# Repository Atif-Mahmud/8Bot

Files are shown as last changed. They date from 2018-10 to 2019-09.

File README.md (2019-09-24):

<h1 align="center">
    <br>
    <a href="#">8Bot</a>
    <br>
    8Bot
    <br>
</h1>



<h4 align="center">Autonomous Pool Robot using Computer Vision</h4>

<h5 align="center">By: Atif Mahmud and Ethan Guo</h5>

<p align="center">
    <a href="http://python.org/">
        
    </a>
    <a href="#">
        
    </a>
    <a href="#">
        
    </a>
</p>

<p align="center">
    <a href="#procedures">Background and Motivation</a> •
    <a href="#procedures">Procedures</a> •
    <a href="#related-works">Related Works</a> •
    <a href="#learning-goals">Learning Goals</a> •
    <a href="#engineering-goals">Engineering Goals</a> •
    <a href="#license">License</a>
</p>

# Background and Motivation

# Procedures
## Dependencies
### Python Libraries
The projects primary language is python. Input parsing, computer vision, and
pathfinding are executed by python clients. The
[OpenCV-Python](https://docs.opencv.org/3.4.3/index.html) wrapper is used along
with [Numpy](http://www.numpy.org/) to do the various computer vision and
matrix operations this project employs.

#### Install Python-OpenCV
```shell
sudo apt-get install python-opencv
```

#### Install Pip
```shell
sudo apt-get install python-pip
```

#### Install Numpy
```shell
pip install numpy
```

### MQTT Broker
This project relies on low latency publisher/subscriber based data transfer. To
do this we employ MQTT. MQTT (Message Queuing Telemetry Transport) is an ISO
Standard messaging protocol commonly used in IOT applications. The one caveat
is that its publish/subscriber message pattern requires a persistent broker.
For the purposes of this project we employ the open source MQTT broker [Eclipse
Mosquitto](https://mosquitto.org).

#### Install Broker (Ubuntu)

(Ubuntu 12^)
```shell
sudo apt install mosquitto
```

(Older versions of Ubuntu)
```shell
sudo apt-add-repository ppa:mosquitto-dev/mosquitto-ppa
sudo apt-get update
```

#### Install Python MQTT Client Library
```shell
pip install paho-mqtt
```

# Learning Goals
- [ ] Continuous Integration
- [x] MQTT Protocol

# Engineering Goals
- [ ] Fast robot messaging infrastructure
- [ ] Robust object classification
- [ ] Robust environment description
- [ ] Robust localization

# Related Works

# License

GNU GENERAL PUBLIC LICENSE
Version 3, 29 June 2007

Refer to LICENSE.txt for full details

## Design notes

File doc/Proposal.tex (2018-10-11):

\documentclass[11pt]{article}
\usepackage[margin=1in]{geometry}
\usepackage[utf8]{inputenc}
\setlength{\parskip}{8pt}
\setlength{\parindent}{0pt}
\usepackage{titling}
\setlength{\droptitle}{-1in}

\usepackage{titlesec}
\titlespacing\section{0pt}{0pt plus 4pt minus 4pt}{0pt plus 4pt minus 4pt}
\titlespacing\subsection{0pt}{0pt plus 4pt minus 4pt}{0pt plus 4pt minus 4pt}
\titlespacing\subsubsection{0pt}{0pt plus 4pt minus 4pt}{0pt plus 4pt minus 4pt}

\title{SE101 Lab Project Proposal \vspace{-12pt}}
\author{Ethan Guo, Atif Mahmud \hskip 5em 11 October 2018}
\date{\vspace{-12pt}}

\begin{document}
\pagenumbering{gobble}

\maketitle
\vspace{-0.625in}

\section*{Introduction}

We aim to create a small mobile robot capable of playing pool.

Ideally, the end goal will be a robot with a wheeled base that travels across the surface of the pool table to line up with the cue ball, then use a solenoid actuator to shoot the cue ball such that it hits another pool ball into a pocket. This will be accomplished with the help of a overhead camera mounted above the pool table. 

\section*{Software}

We will structure our software components into nodes, based loosely on the ROS paradigm. The computer vision node will take in camera input and use OpenCV to determine the position of the robot and pool balls. The robot control node, written in Python, will perform pathfinding, and send commands to move the robot. Finally, the user interface node, written using Angular will display the current board environment from the computer vision node and send REST requests to the robot control node to preform actions.

\section*{Hardware}

We will be using the following hardware (* denotes items we need to purchase):
\begin{itemize}
    \setlength{\itemsep}{0pt} %
    \setlength{\parskip}{0pt} %
    \setlength{\parsep}{0pt} %
    \vspace{-0.125in}
    \item Arduino Uno or Nano microcontroller
    \item HC-05 Bluetooth Transceiver
    \item Solenoid actuator to shoot cue balls *
    \item $4 \times$ Robotshop gear motors or continuous servos *
    \item $4 \times$ Robotshop omni wheels *
    \item USB webcam *
\end{itemize}

\vspace{-8pt}
Time-permitting, we would ideally like to design and fabricate a PCB to integrate all the circuitry.

\section*{Challenges}

On the software side, the biggest challenge will be in the computer vision task. This includes detecting and locating pool balls and the robot itself, and most critically, classifying striped vs. solid balls.
Fortunately, the pool table is a relatively easy environment for computer vision tasks, since the background is a static solid colour, and the objects are a consistent size and shape and mostly solid colours.

Another challenge will be writing the pathfinding and closed-loop control system to move the robot into the desired program, while navigating around obstacles (other pool balls).

On the hardware side, we will most likely need to build the robot base and drive system from scratch, which will be time-consuming and will likely require plenty of troubleshooting.

\section*{Prototype}

We will be building this project as a evolutionary prototype. With so many different systems to integrate, we will be working in a horizontal paradigm. By the prototype demo day, we aim to have a working mobile base, very basic functionality in each of the three major software components (computer vision, robot control, user interface), and a functional skeleton for communication between the relevant nodes (including the hardware components).

% https://github.com/patricklam/se101-f18/blob/master/lab/se101-lab-project.pdf

\end{document}

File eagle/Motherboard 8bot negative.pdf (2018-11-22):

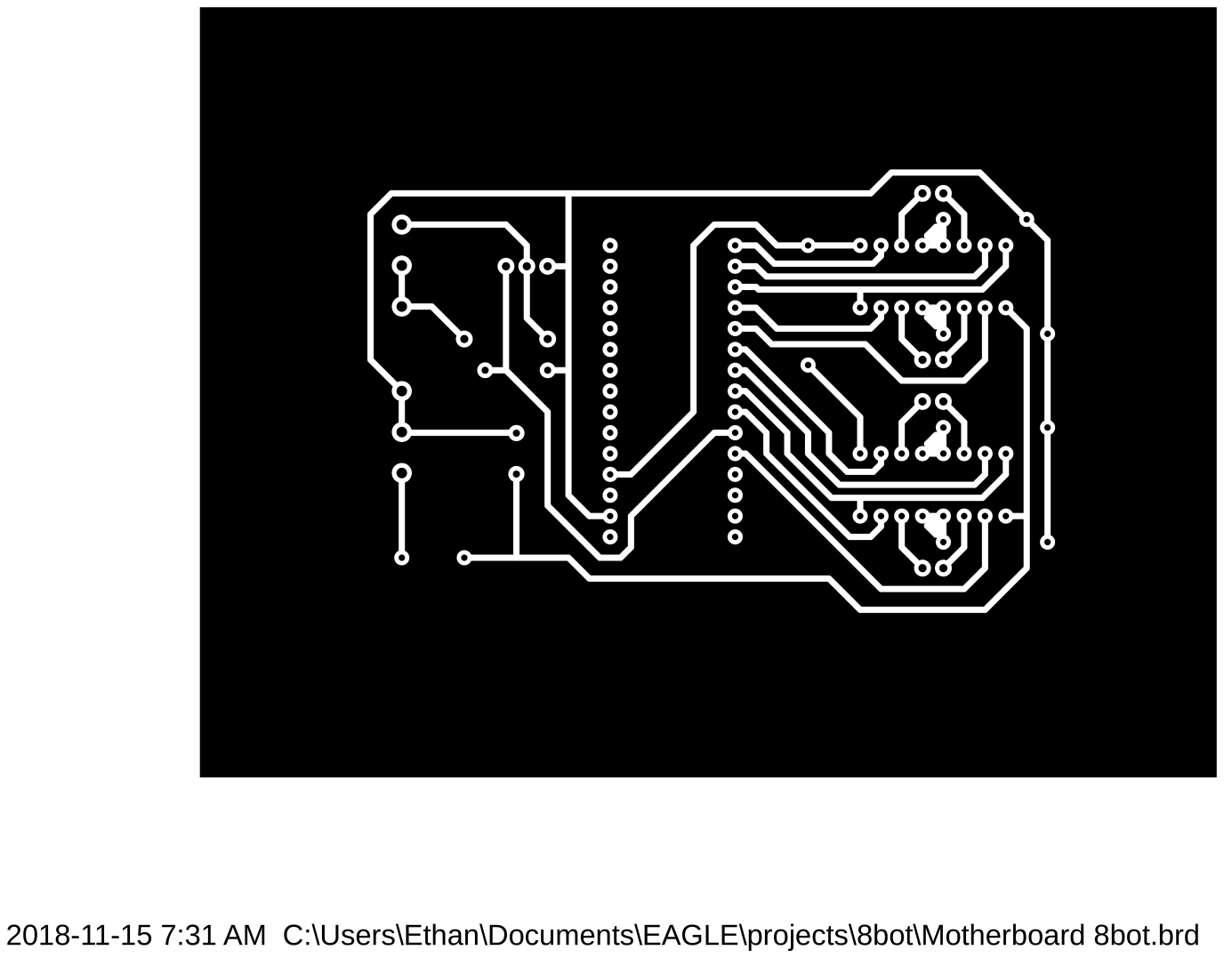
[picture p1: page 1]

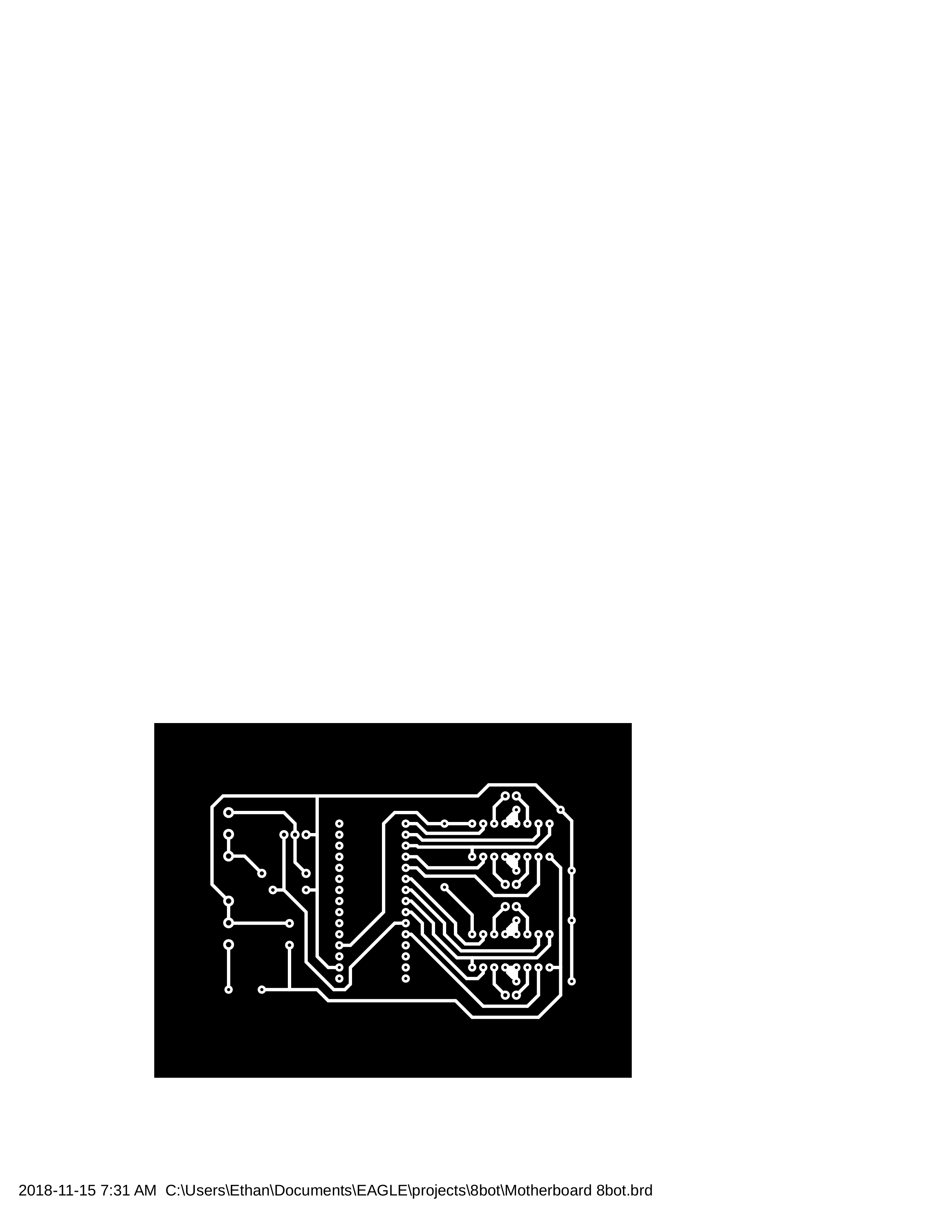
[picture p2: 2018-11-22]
eagle/Motherboard 8bot negative.png

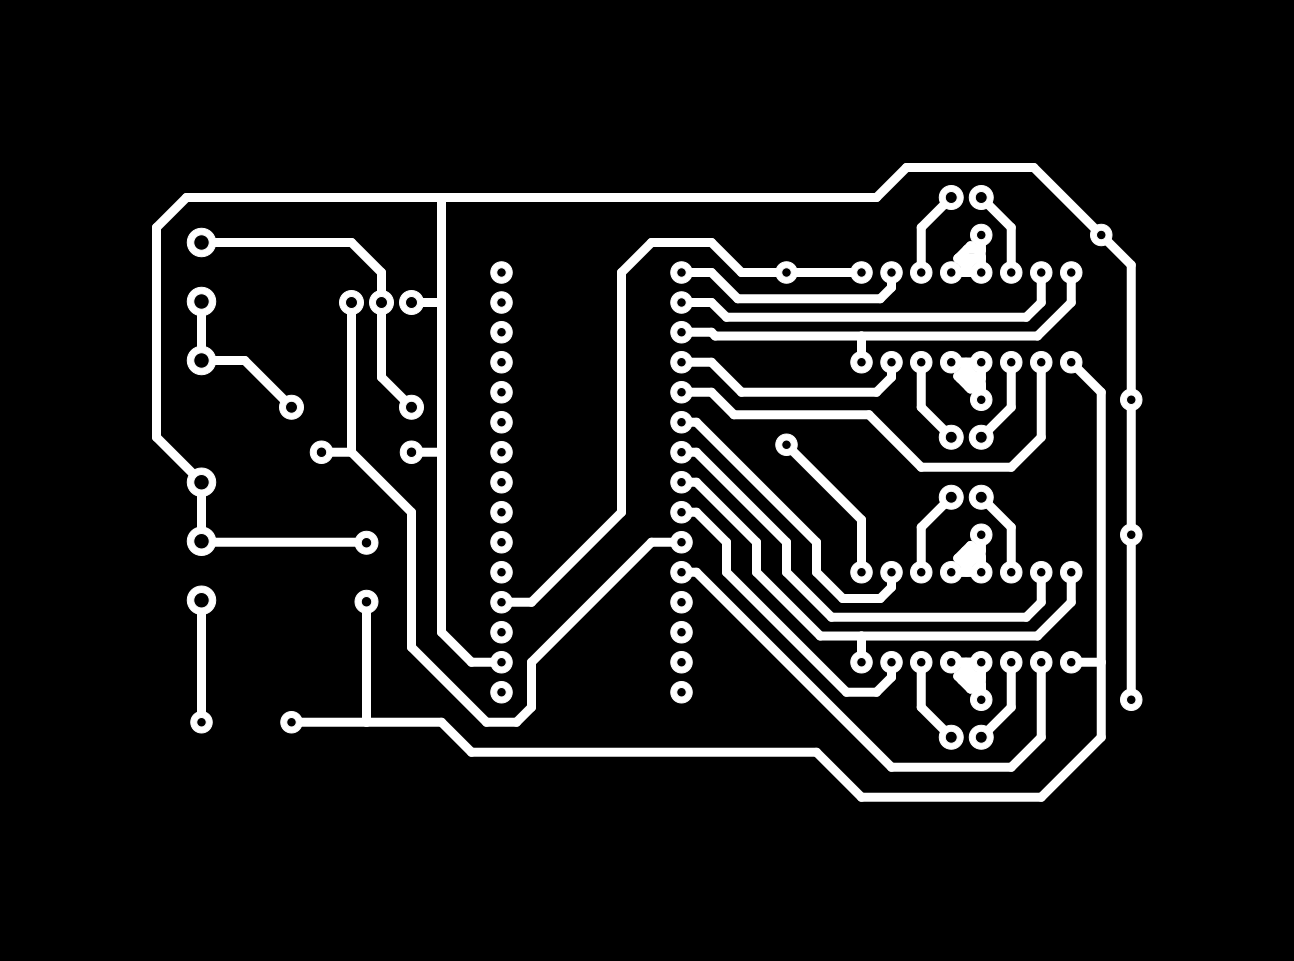
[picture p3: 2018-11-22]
eagle/Motherboard 8bot negative isolated.png

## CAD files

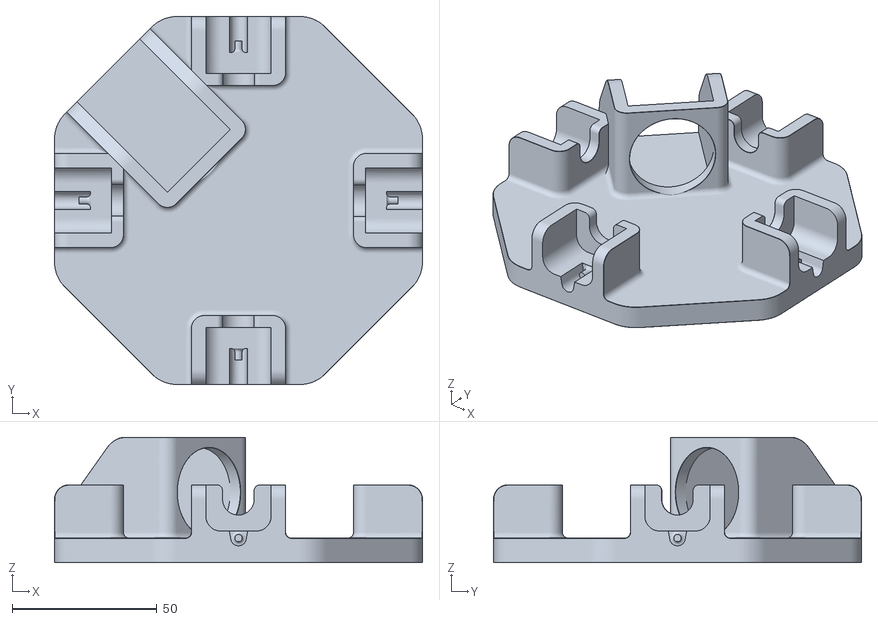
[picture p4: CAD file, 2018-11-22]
3D Models/Frame.stl
127.3 x 127.3 x 43.4

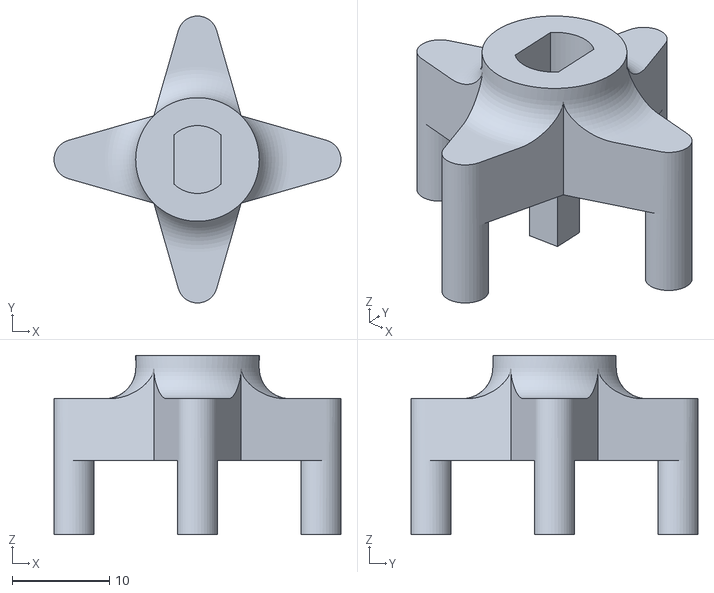
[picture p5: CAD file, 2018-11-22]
3D Models/Wheel Mount.stl
29.5 x 29.5 x 18.4

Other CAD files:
3D Models/Assembly.iam
3D Models/Frame.ipt
3D Models/Motor Solarbotics GM3/GM3-driver_side-1.ipt
3D Models/Motor Solarbotics GM3/GM3-encoder_side-1.ipt
3D Models/Motor Solarbotics GM3/GMstrap2.ipt
3D Models/Motor Solarbotics GM3/RM3-regular motor.ipt
3D Models/Motor Solarbotics GM3/Solarbotics-GM3.iam
3D Models/Motor Solarbotics GM3/encoder.ipt
3D Models/Motor Solarbotics GM3/output shaft.ipt
3D Models/Motor Solarbotics GM3/screw_head1.ipt
3D Models/Solenoid Arm.ipt
3D Models/Solenoid Body.ipt
3D Models/Solenoid.iam
3D Models/Solenoid.ipt
3D Models/Wheel Mount.ipt
3D Models/Wheel VEX 228-2536/228-2536-001-1.ipt
3D Models/Wheel VEX 228-2536/228-2536-002-1.ipt
3D Models/Wheel VEX 228-2536/228-2536-003-1.ipt
3D Models/Wheel VEX 228-2536/228-2536-004-1.ipt
3D Models/Wheel VEX 228-2536/ROLLER-2.iam
3D Models/Wheel VEX 228-2536/Wheel VEX 228-2536.iam

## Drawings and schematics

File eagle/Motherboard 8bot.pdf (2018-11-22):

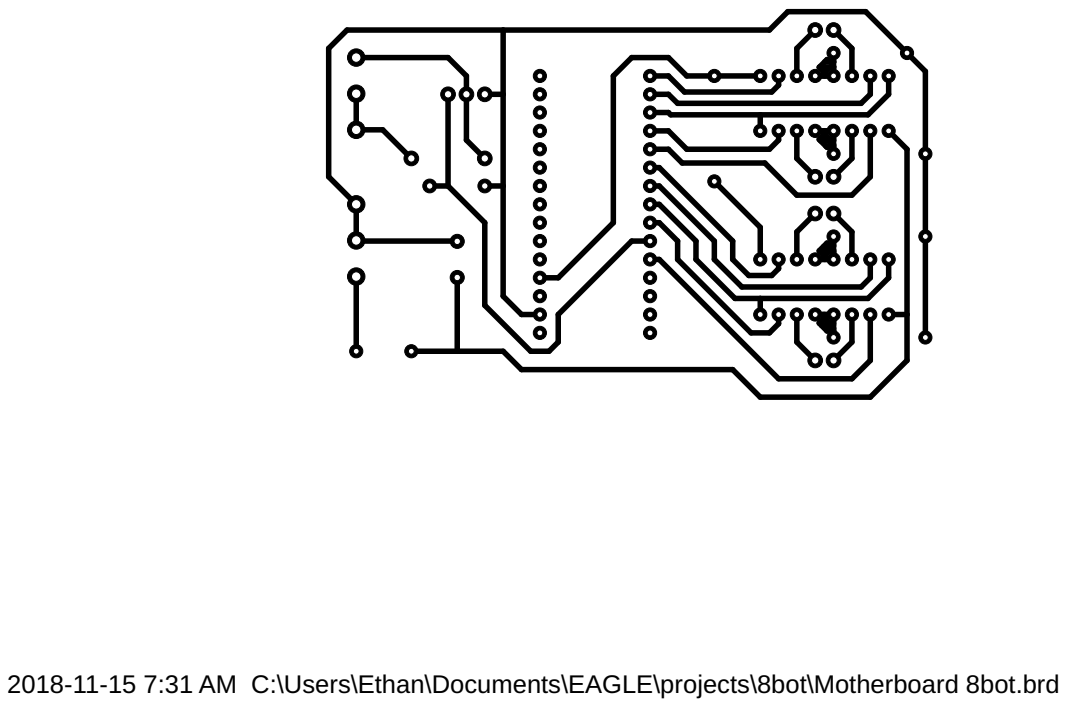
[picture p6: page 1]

2018-11-15 7:31 AM C:\Users\Ethan\Documents\EAGLE\projects\8bot\Motherboard 8bot.brd

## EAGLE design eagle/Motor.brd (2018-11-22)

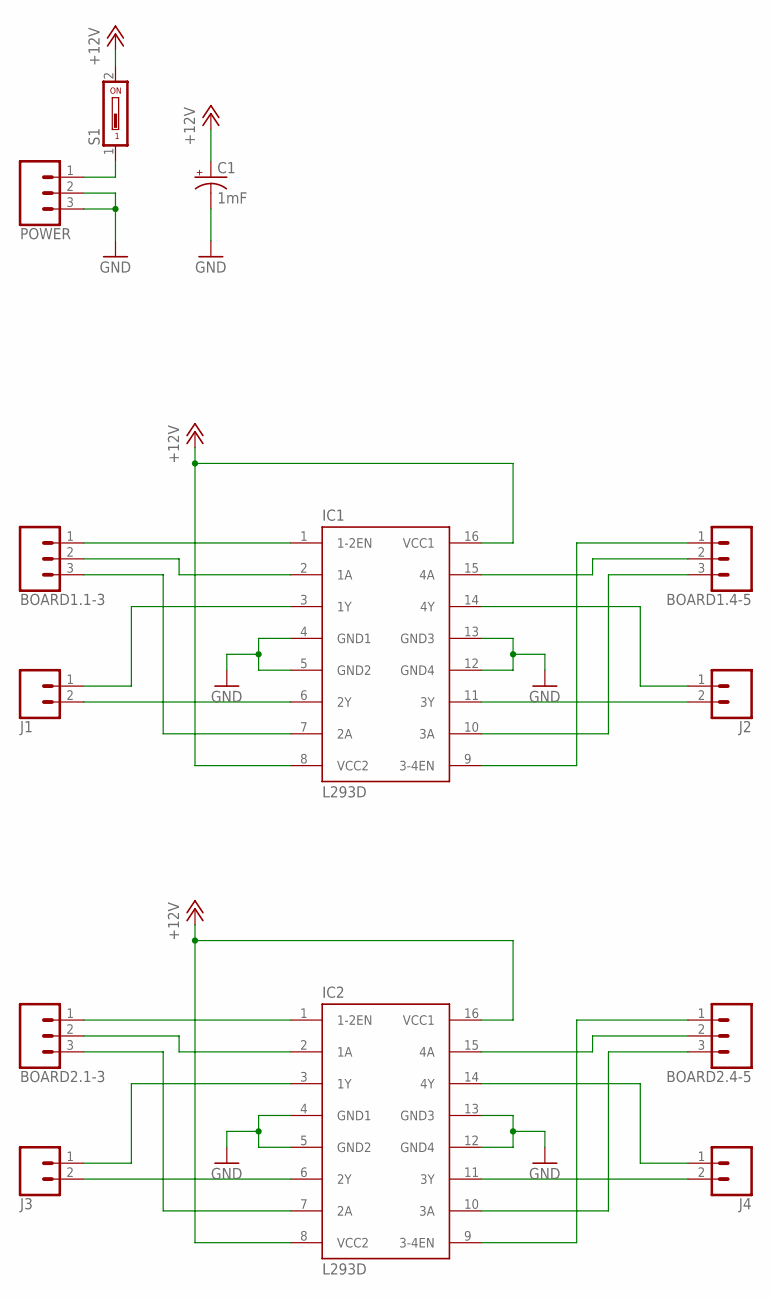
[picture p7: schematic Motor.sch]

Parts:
BOARD1.1-3, BOARD1.4-5, BOARD2.1-3, BOARD2.4-5: CONN_03; 1X03
C1: 1mF; CPOL-RADIAL-5MM-10MM
IC1, IC2: L293D; DIL16
J1, J2, J3, J4: CONN_02; 1X02
POWER: CONN_03; 1X03
S1: DS01; DS-01

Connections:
+9V: C1.+, IC1.8 (VCC2), IC1.16 (VCC1), IC2.8 (VCC2), IC2.16 (VCC1), S1.2
EN1: BOARD1.1-3.1, IC1.1 (1-2EN)
EN2: BOARD2.1-3.1, IC2.1 (1-2EN)
GND: C1.-, IC1.4 (GND1), IC1.5 (GND2), IC1.12 (GND4), IC1.13 (GND3), IC2.4 (GND1), IC2.5 (GND2), IC2.12 (GND4), IC2.13 (GND3), POWER.2, POWER.3
unnamed: IC1.3 (1Y), J1.1
unnamed: IC1.6 (2Y), J1.2
unnamed: IC1.14 (4Y), J2.1
unnamed: IC1.11 (3Y), J2.2
unnamed: BOARD1.1-3.2, IC1.2 (1A)
unnamed: BOARD1.1-3.3, IC1.7 (2A)
unnamed: BOARD1.4-5.3, IC1.10 (3A)
unnamed: BOARD1.4-5.2, IC1.15 (4A)
unnamed: IC2.3 (1Y), J3.1
unnamed: IC2.6 (2Y), J3.2
unnamed: IC2.14 (4Y), J4.1
unnamed: IC2.11 (3Y), J4.2
unnamed: BOARD2.1-3.2, IC2.2 (1A)
unnamed: BOARD2.1-3.3, IC2.7 (2A)
unnamed: BOARD2.4-5.1, IC2.9 (3-4EN)
unnamed: BOARD1.4-5.1, IC1.9 (3-4EN)
unnamed: BOARD2.4-5.3, IC2.10 (3A)
unnamed: BOARD2.4-5.2, IC2.15 (4A)
unnamed: POWER.1, S1.1

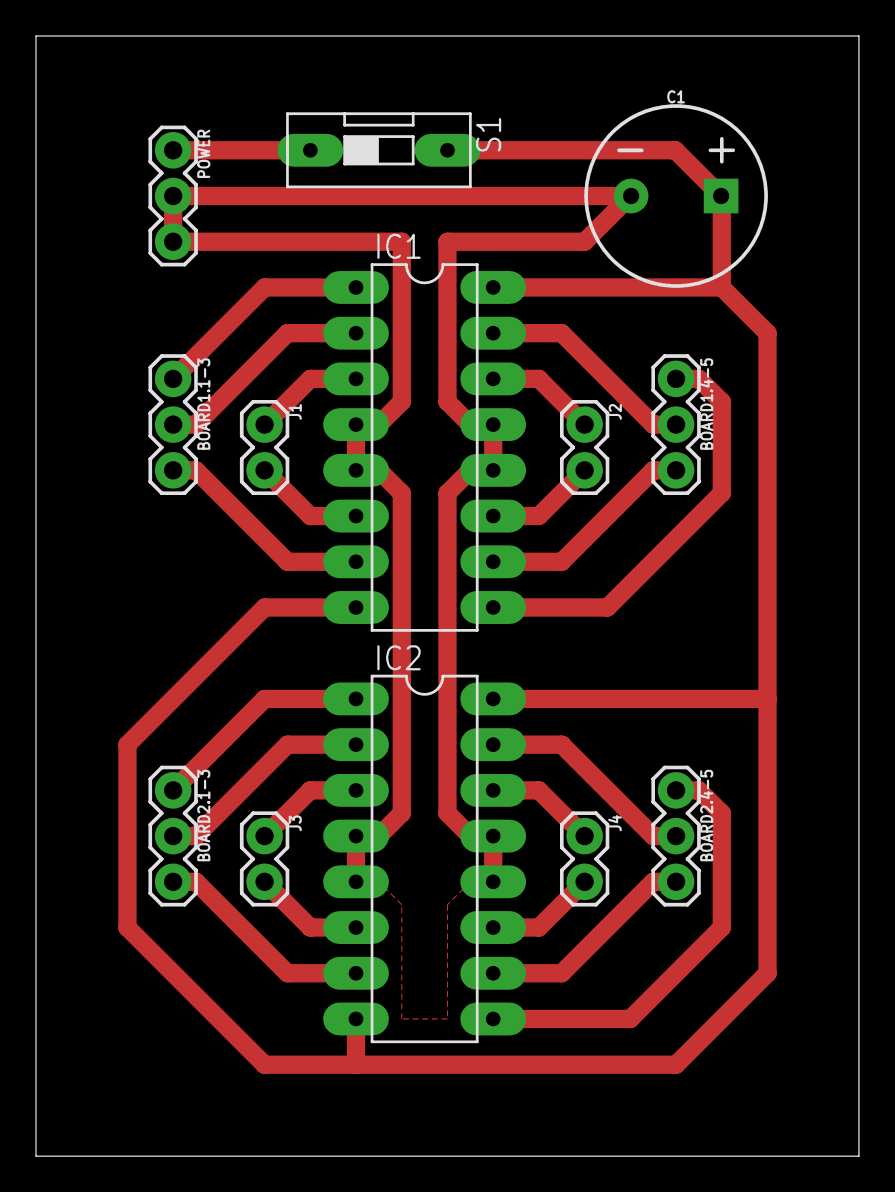
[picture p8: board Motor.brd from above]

Board: 2 copper layers, 45.7 x 62.2 mm, 13 parts (0 on the bottom side), 23 nets.

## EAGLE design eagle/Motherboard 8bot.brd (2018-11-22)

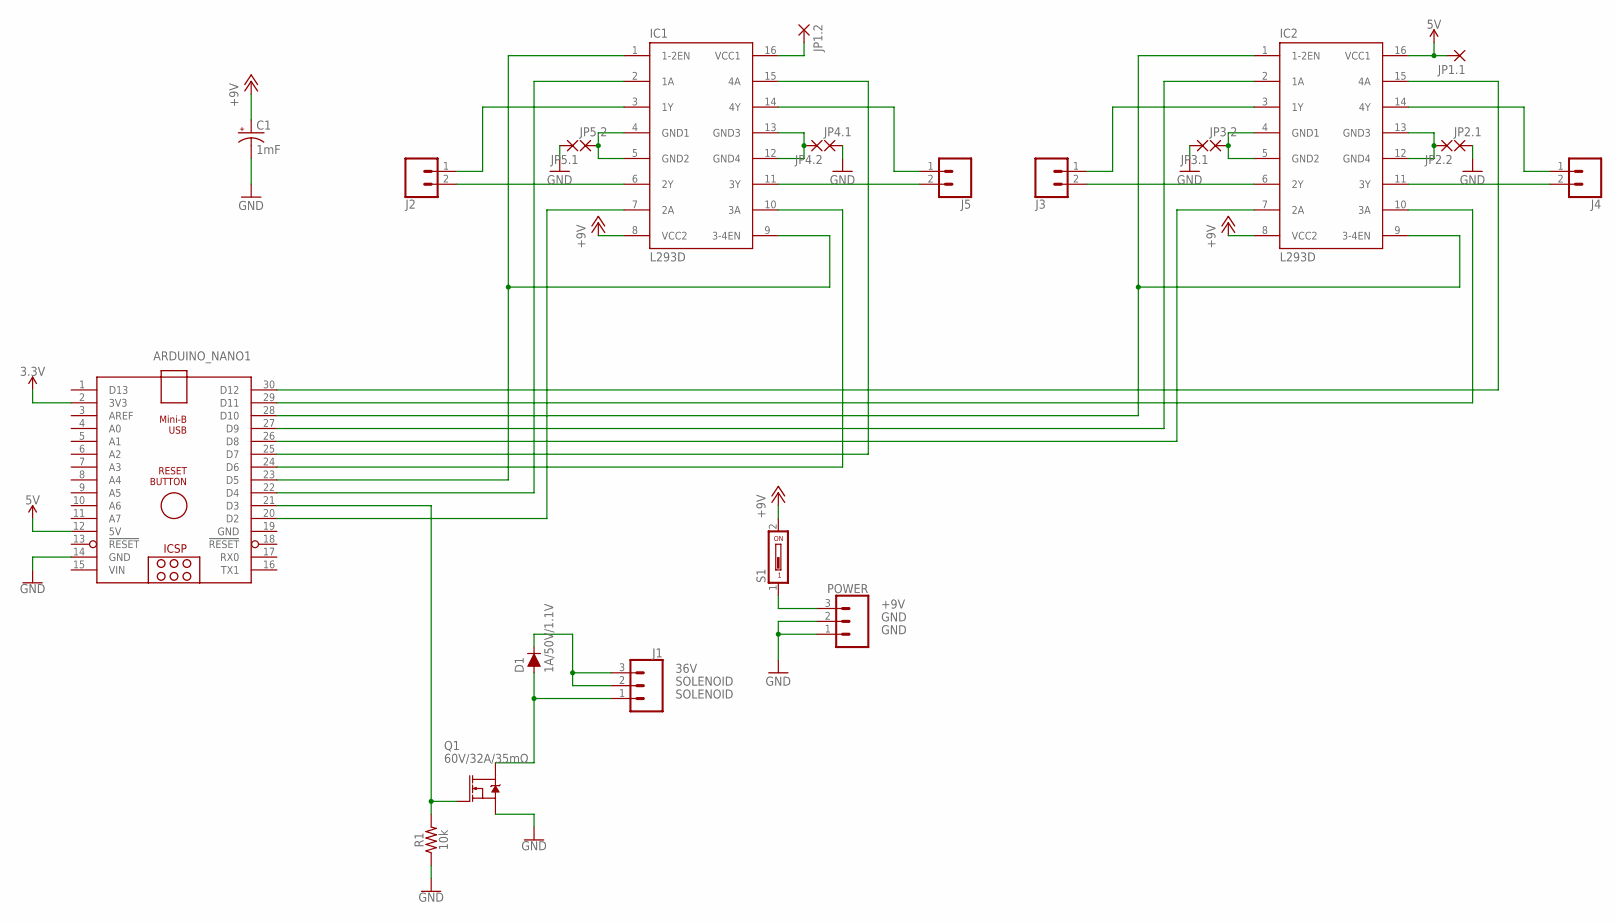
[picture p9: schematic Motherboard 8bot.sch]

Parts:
ARDUINO_NANO1: ARDUINO_NANO
C1: 1mF; CPOL-RADIAL-5MM-10MM
D1: 1A/50V/1.1V; DIODE-1N4001
IC1, IC2: L293D; DIL16
J1: CONN_03-SCREW-5MM; SCREWTERMINAL-5MM-3
J2, J3, J4, J5: CONN_02; 1X02
JP1.1, JP1.2, JP2.1, JP2.2, JP3.1, JP3.2, JP4.1, JP4.2, JP5.1, JP5.2: 1,6/0,8
POWER: CONN_03-SCREW-5MM; SCREWTERMINAL-5MM-3
Q1: 60V/32A/35mΩ; TO220V
R1: 10k; AXIAL-0.3
S1: DS01; DS-01

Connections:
3.3V: ARDUINO_NANO1.2 (3V3)
5V: ARDUINO_NANO1.12 (5V), IC2.16 (VCC1), JP1.1.1
36V: D1.C, J1.2, J1.3
+9V: C1.+, IC1.8 (VCC2), IC2.8 (VCC2), S1.2
EN1: ARDUINO_NANO1.23 (D5), IC1.1 (1-2EN), IC1.9 (3-4EN)
EN2: ARDUINO_NANO1.28 (D10), IC2.1 (1-2EN), IC2.9 (3-4EN)
GND: ARDUINO_NANO1.14 (GND), ARDUINO_NANO1.19 (GND), C1.-, JP2.1.1, JP3.1.1, JP4.1.1, JP5.1.1, POWER.1, POWER.2, Q1.3 (S), R1.P$1 (1)
unnamed: ARDUINO_NANO1.21 (D3), Q1.1 (G), R1.P$2 (2)
unnamed: IC1.3 (1Y), J2.1
unnamed: IC1.6 (2Y), J2.2
unnamed: IC1.14 (4Y), J5.1
unnamed: IC1.11 (3Y), J5.2
unnamed: ARDUINO_NANO1.20 (D2), IC1.7 (2A)
unnamed: ARDUINO_NANO1.22 (D4), IC1.2 (1A)
unnamed: ARDUINO_NANO1.24 (D6), IC1.10 (3A)
unnamed: IC2.3 (1Y), J3.1
unnamed: IC2.6 (2Y), J3.2
unnamed: IC2.14 (4Y), J4.1
unnamed: IC2.11 (3Y), J4.2
unnamed: IC1.16 (VCC1), JP1.2.1
unnamed: ARDUINO_NANO1.27 (D9), IC2.2 (1A)
unnamed: ARDUINO_NANO1.25 (D7), IC1.15 (4A)
unnamed: ARDUINO_NANO1.29 (D11), IC2.10 (3A)
unnamed: ARDUINO_NANO1.26 (D8), IC2.7 (2A)
unnamed: ARDUINO_NANO1.30 (D12), IC2.15 (4A)
unnamed: IC1.4 (GND1), IC1.5 (GND2), JP5.2.1
unnamed: POWER.3, S1.1
unnamed: IC1.12 (GND4), IC1.13 (GND3), JP4.2.1
unnamed: IC2.4 (GND1), IC2.5 (GND2), JP3.2.1
unnamed: IC2.12 (GND4), IC2.13 (GND3), JP2.2.1
SOLENOID: D1.A, J1.1, Q1.2 (D)
VIN: ARDUINO_NANO1.15 (VIN)

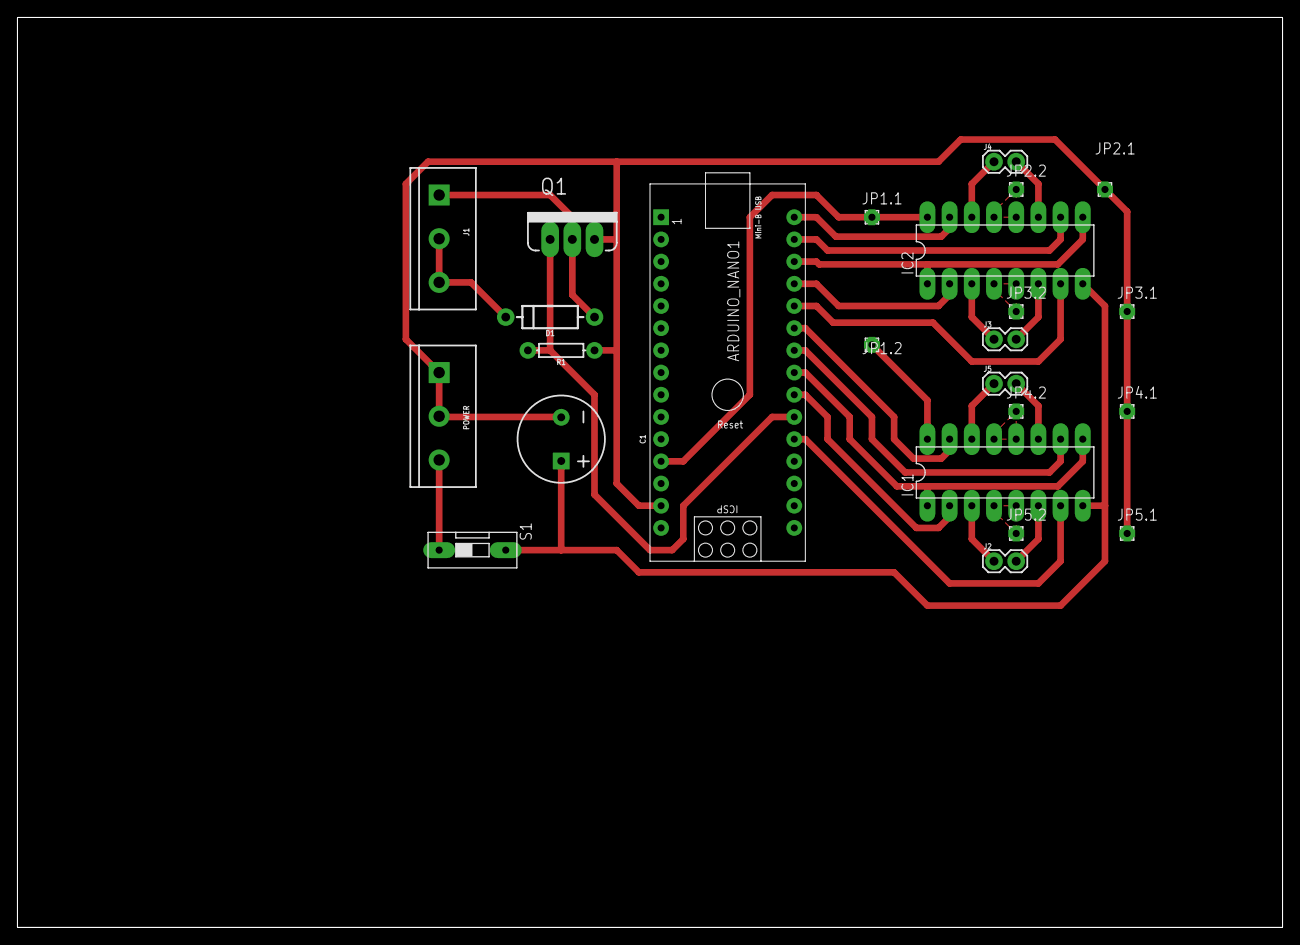
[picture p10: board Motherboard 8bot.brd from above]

Board: 2 copper layers, 144.8 x 104.1 mm, 24 parts (0 on the bottom side), 30 nets.

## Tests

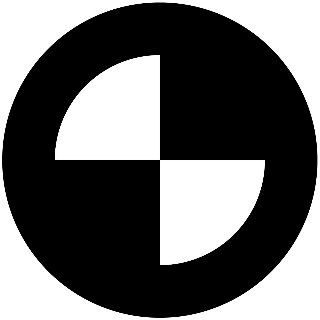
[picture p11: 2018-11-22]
computer_vision_node/img/calibration_320.png

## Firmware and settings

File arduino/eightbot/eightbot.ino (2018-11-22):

// #define DEBUG_ECHO


#define EN_12 5
#define M1_F  2
#define M1_B  4
#define M2_F  7
#define M2_B  6

#define EN_34 10
#define M3_F  9
#define M3_B  8
#define M4_F  11
#define M4_B  12

#define SOLENOID  3
#define LED  13

#define SOLENOID_DURATION 500 // ms

#define GET_BIT(c, bit) (c >> bit & 1)

int solenoid_timer = 0;

char command = 0;
char data = 0;

void setup() {
  pinMode(EN_12, OUTPUT);
  pinMode(M1_F, OUTPUT);
  pinMode(M1_B, OUTPUT);
  pinMode(M2_F, OUTPUT);
  pinMode(M2_B, OUTPUT);
  pinMode(EN_34, OUTPUT);
  pinMode(M3_F, OUTPUT);
  pinMode(M3_B, OUTPUT);
  pinMode(M4_F, OUTPUT);
  pinMode(M4_B, OUTPUT);
  pinMode(SOLENOID, OUTPUT);
  pinMode(LED, OUTPUT);

  digitalWrite(EN_12, HIGH);
  digitalWrite(EN_34, HIGH);

  Serial.begin(9600);
  Serial.println("8bot");
}

void loop() {
  if (Serial.available()) {
    if (command == 0) {
      command = Serial.read();
    }
    else {
      data = Serial.read();

      #ifdef DEBUG_ECHO
        Serial.print(command);
        Serial.print(" ");
        Serial.println(data);
      #endif

      if (command == 'M') {
        digitalWrite(M1_F, GET_BIT(data, 7));
        digitalWrite(M1_B, GET_BIT(data, 6));
        digitalWrite(M2_F, GET_BIT(data, 5));
        digitalWrite(M2_B, GET_BIT(data, 4));
        digitalWrite(M3_F, GET_BIT(data, 3));
        digitalWrite(M3_B, GET_BIT(data, 2));
        digitalWrite(M4_F, GET_BIT(data, 1));
        digitalWrite(M4_B, GET_BIT(data, 0));
      }
      else if (command == 'A') {
        analogWrite(EN_12, data);
      }
      else if (command == 'B') {
        analogWrite(EN_34, data);
      }
      else if (command == 'S') {
        solenoid_timer = SOLENOID_DURATION;
        digitalWrite(SOLENOID, HIGH);
        digitalWrite(LED, HIGH);
      }
      command = 0;
    }
  }

  if (solenoid_timer > 0) solenoid_timer--;
  else {digitalWrite(SOLENOID, LOW); digitalWrite(LED, LOW);}

  delay(1);
}

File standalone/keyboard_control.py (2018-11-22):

import logging

import serial

SERIAL_PORT = "COM4"
SERIAL_BAUDRATE = 9600

logging.basicConfig(level=logging.DEBUG)
logger = logging.getLogger("Serial")

def scale(x, inLow, inHigh, outLow, outHigh):
	return (x - inLow) * (outHigh - outLow) / (inHigh - inLow) + outLow

def clamp(x, low, high):
	return max(low, min(high, x))

def scale_clamp(x, inLow, inHigh, outLow, outHigh):
	return clamp(scale(x, inLow, inHigh, outLow, outHigh), outLow, outHigh)

logger.debug("Serial: Attempting connection at (\"%s\", %d)" % (SERIAL_PORT, SERIAL_BAUDRATE))
s = serial.Serial(SERIAL_PORT, SERIAL_BAUDRATE, timeout=5)
logger.info("Serial: Connected.")

def get_next_message():
	input_ = input(">")
	input_ = "".join(input_.split()) # Remove whitespace

	if input_ == "":
		return b"M\x00"

	if input_ == "w":
		return b"M" + bytes([0b10101010])
	if input_ == "s":
		return b"M" + bytes([0b01010101])
	if input_ == "a":
		return b"M" + bytes([0b01011010])
	if input_ == "d":
		return b"M" + bytes([0b10100101])
	if input_ == "q":
		return b"M" + bytes([0b01100110])
	if input_ == "e":
		return b"M" + bytes([0b10011001])

	if input_ == "S":
		return b"S0"

	if ord("0") <= ord(input_[0]) <= ord("9"):
		speed = int(input_[0]) * 32
		speed = min(speed, 255)
		return (b"A" + bytes([speed])
			  + b"B" + bytes([speed]))

	if not input_[0].isupper():
		logger.error("Invalid command!")
		return

	if input_[1] in ("x", "X"): # Hex
		dataByte = int(input_[2:4], base=16)
	elif input_[1] in ("b", "B"): # Binary
		dataByte = int(input_[2:10], base=2)
	else: # Decimal
		dataByte = int(input_[1:])

	if dataByte > 255 or dataByte < 0:
		logger.error("Data byte out of range!")
		return

	return bytes([ord(input_[0]), dataByte])

while True:
	message = get_next_message()
	if message:
		logger.debug("Sending message: %s" % message)
		s.write(message)

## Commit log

2018-10-06 ✨ Add empty README file
2018-11-21 Add solenoid_test and (test) 8bot firmware
2018-11-21 Rename arduino/8bot/8bot.ino -> arduino/eightbot/eightbot.ino
2018-11-22 Create loadImage method in calibration class
    References: #13
2018-11-22 Fixed taking commands, add debug stuff (LED and Serial echo)
    [eightbot.ino]
2018-11-22 Implement calibrate class
    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
2018-11-22 Fix: Turn off DEBUG_ECHO Serial echo flag
    [eightbot.ino]
2018-11-22 Add all eagle (PCB) and 3D print files
    [228-2536-001-1.ipt, 228-2536-002-1.ipt, 228-2536-003-1.ipt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]
2018-11-22 Improve calibration with contours
    References: #19

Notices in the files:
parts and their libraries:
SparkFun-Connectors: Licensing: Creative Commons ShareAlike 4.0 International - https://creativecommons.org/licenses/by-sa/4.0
